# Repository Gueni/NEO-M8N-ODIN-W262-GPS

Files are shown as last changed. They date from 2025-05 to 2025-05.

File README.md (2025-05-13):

# GPS Module with PS/2 Programming Trigger
This project features a dual GPS/Bluetooth PCB design using:

- **NEO-M8N** (Part: `672-NEO-M8N-0TR-ND`) for GNSS positioning  
- **ODIN-W262** (Part: `672-ODIN-W262-05BTR-ND`) for Bluetooth communication  
- A custom **PS/2-based connector** to enable programming mode automatically via pin shorting

<p align="center">
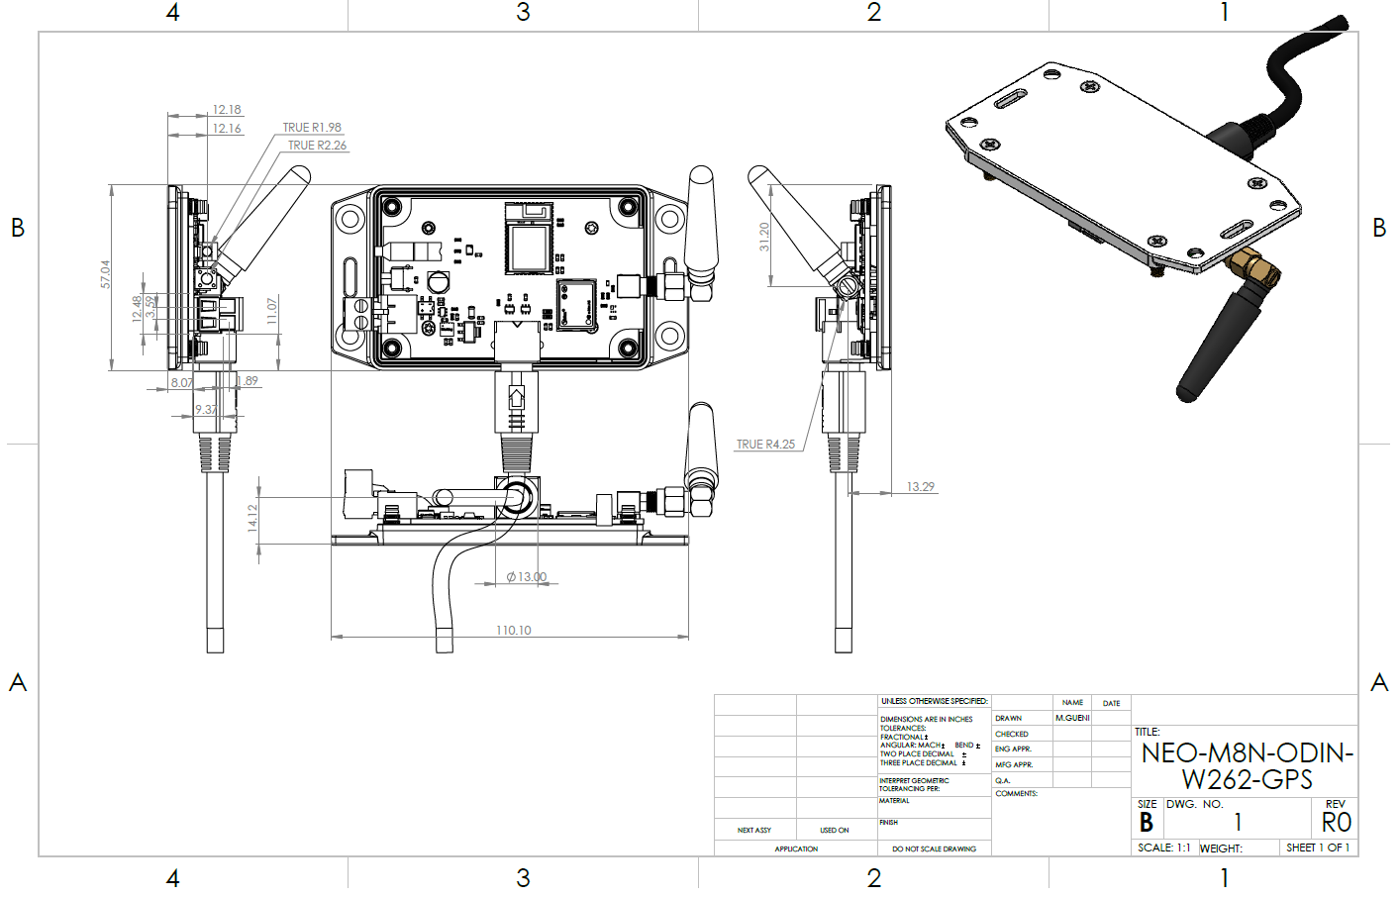
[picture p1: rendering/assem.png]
  
</p>

The system is compact, enclosed, and fully programmable without disassembly — using a smart GND-detection feature via the PS/2 port.

---
<p align="center">
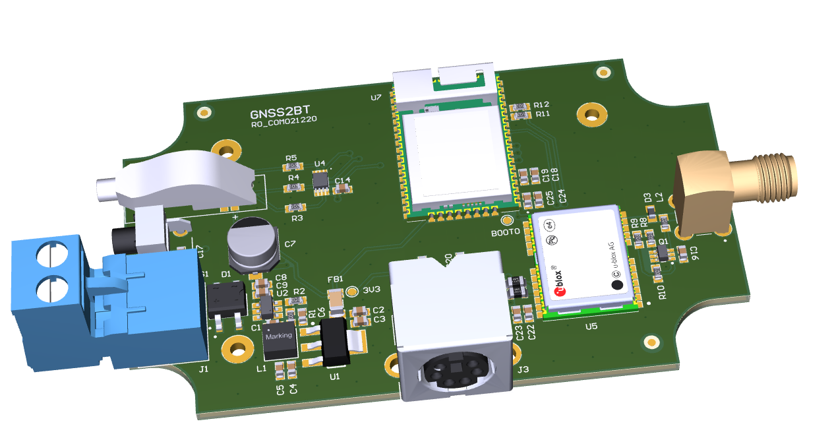
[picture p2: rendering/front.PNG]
  
</p>

## 💡 Features

- **GPS**: Multi-GNSS (GPS, GLONASS, Galileo, BeiDou) via NEO-M8N
- **Bluetooth**: Dual-mode BLE + classic via ODIN-W262
- **Enclosure**: Compact PCB with enclosure support
- **Programming Mode**: Automatically enabled when PS/2 connector is plugged in — GND pin shorts internal detection line
- **Power**: 3.3V operation with onboard LDO regulators
- **I/O**: Exposed UART for debug or data streaming
- **Connector**: 6-pin PS/2 Mini-DIN style programming interface

---

<p align="center">
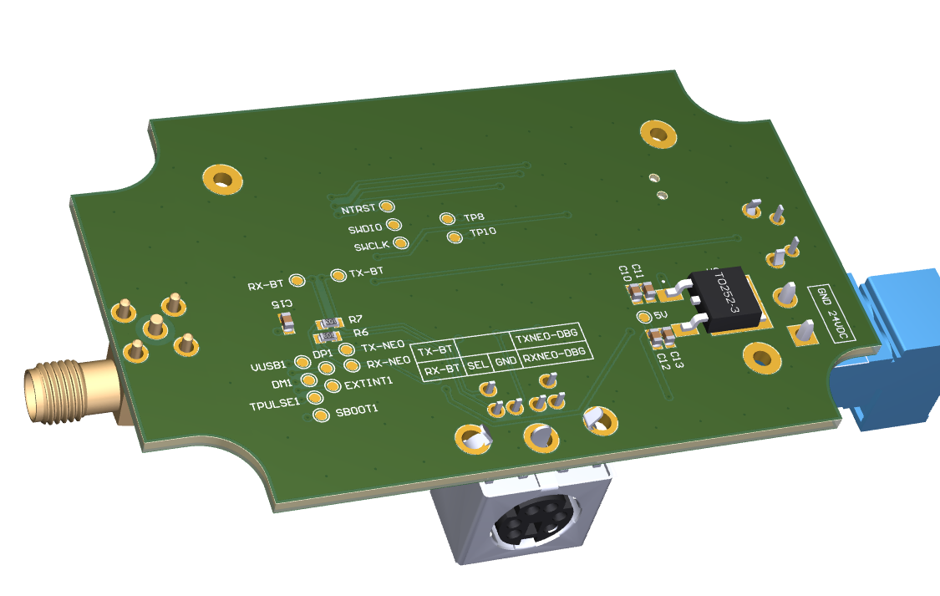
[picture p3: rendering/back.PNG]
  
</p>

## 🔌 Pinout (PS/2 Connector)

| PS/2 Pin | Function |
|---|---|
| Pin 1 | VCC (3.3V) |
| Pin 2 | TX (to programmer) |
| Pin 3 | RX (from programmer) |
| Pin 4 | GND |
| Pin 5 | GND detect (shorted when inserted) |
| Pin 6 | NC / Reserved |

*Ensure the PS/2 plug is inserted fully to engage GND detect pin.*

---

<p align="center">
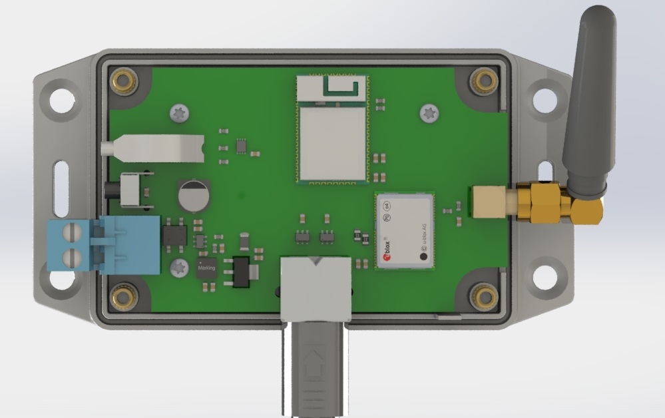
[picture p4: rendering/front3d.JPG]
  
</p>

<p align="center">
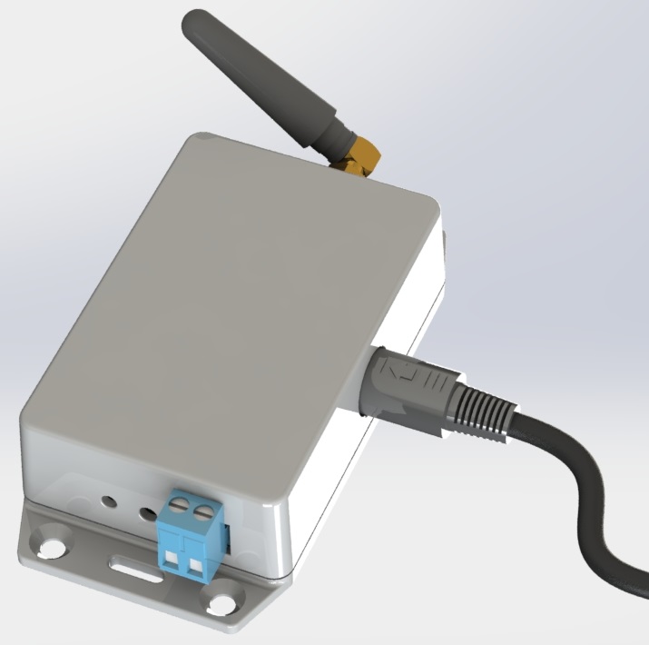
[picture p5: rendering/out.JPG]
  
</p>

<p align="center">
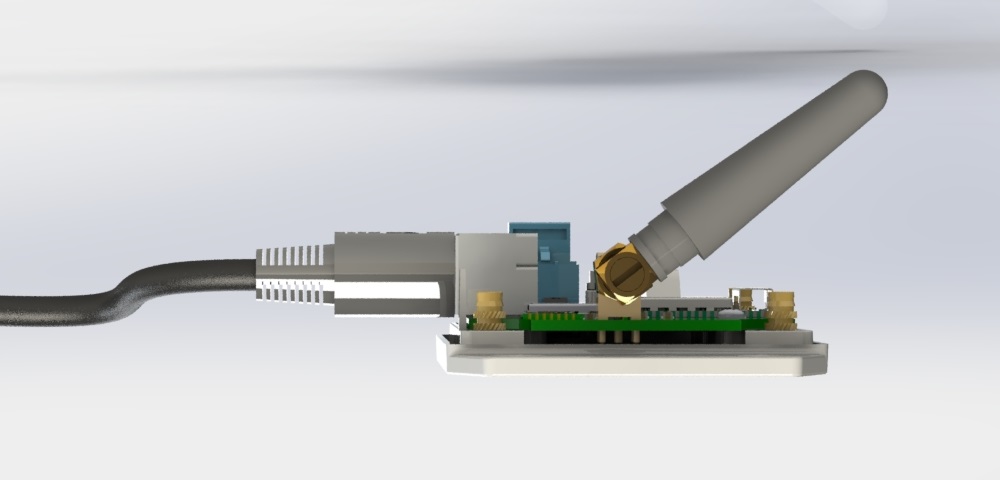
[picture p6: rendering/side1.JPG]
  
</p>

## 🛠 Programming Instructions

1. Plug in the PS/2 connector from the programming device.
2. This triggers programming mode automatically.
3. Use the provided UART interface at 3.3V levels.
4. Flash via standard tools (e.g., STM32CubeProgrammer, esptool.py, depending on MCU).

---

<p align="center">
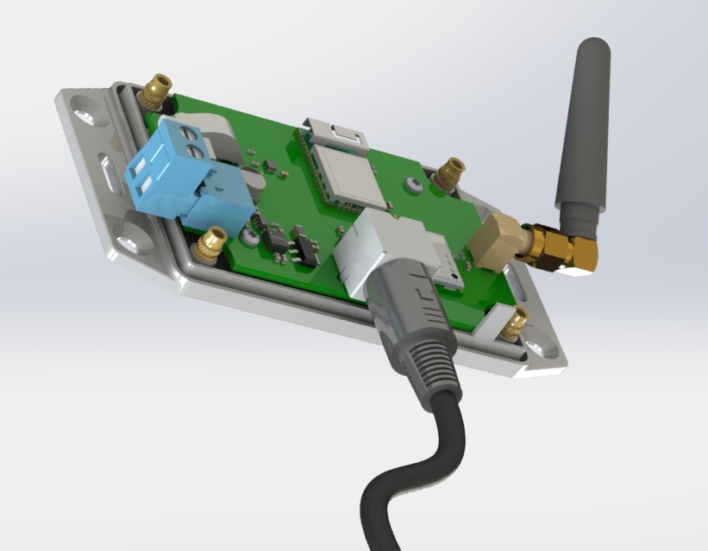
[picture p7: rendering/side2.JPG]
  
</p>

<p align="center">
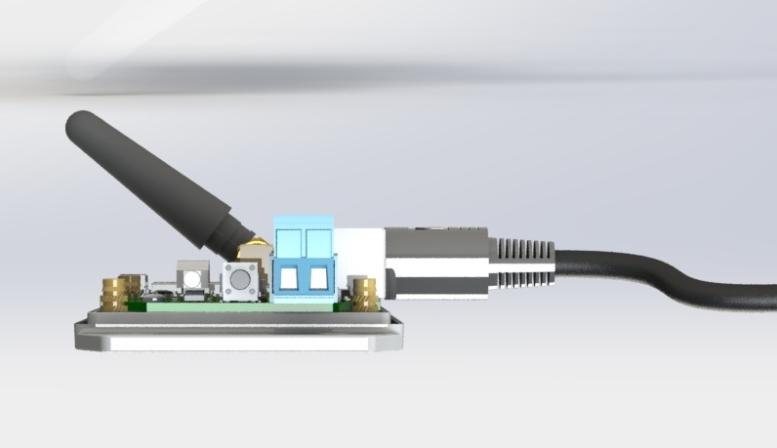
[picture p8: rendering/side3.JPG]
  
</p>

## 🧪 Testing & Debug

- LED indicators show GNSS fix and BT activity
- Test programming mode with multimeter: verify GND detect line goes LOW when PS/2 is inserted
- Firmware should check the GND detect pin at startup to enter bootloader

---

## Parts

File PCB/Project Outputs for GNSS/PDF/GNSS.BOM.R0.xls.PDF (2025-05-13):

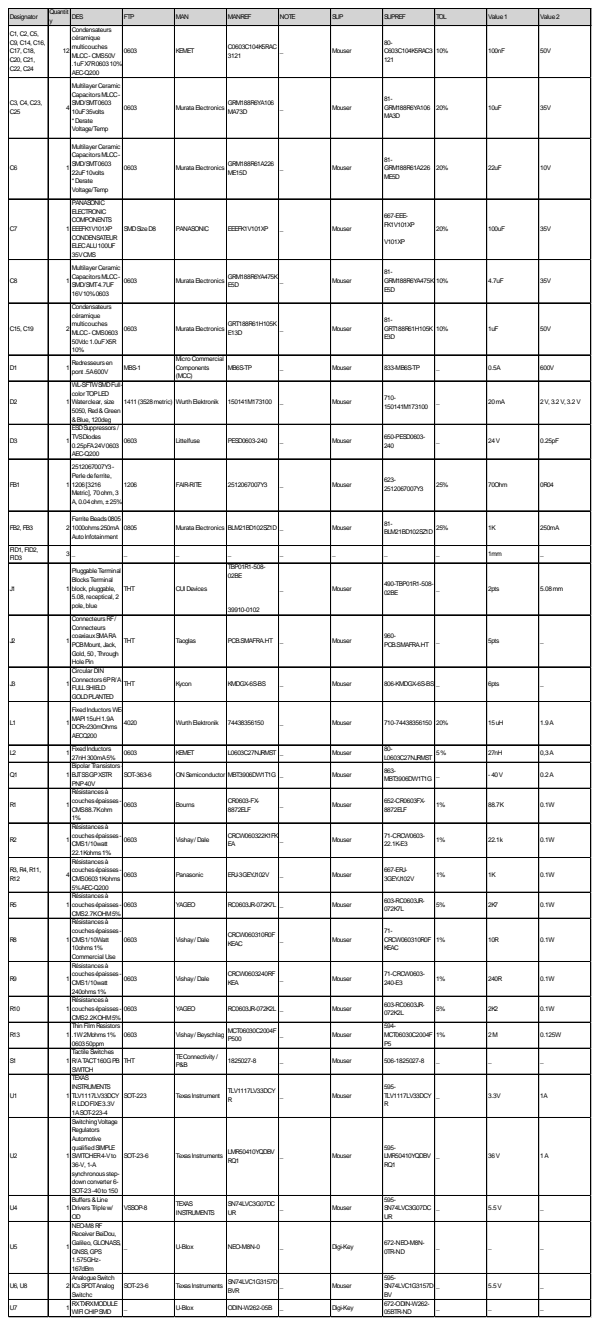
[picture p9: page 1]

Designator | Quantit y | DES | FTP | MAN | MANREF | NOTE | SUP | SUPREF | TOL | Value1 | Value2

C1, C2, C5, C9, C14, C16, C17, C18, C20, C21, C22, C24 | 12 | Condensateurs céramique multicouches MLCC- CMS50V .1uFX7R060310% AEC-Q200 | 0603 | KEMET | C0603C104K5RAC 3121 | _ | Mouser | 80-C603C104K5RAC3 121 | 10% | 100nF | 50V

C3, C4, C23, C25 | | Multilayer Ceramic Capacitors MLCC-SMD/SMT0603 4 10uF35volts *Derate Voltage/Temp | 0603 | MurataElectronics | GRM188R6YA106 MA73D | _ | Mouser | 81-GRM188R6YA106 MA3D | 20% | 10uF | 35V

C6 | | Multilayer Ceramic Capacitors MLCC-1 SMD/SMT0603 22uF10volts *Derate Voltage/Temp | 0603 | MurataElectronics | GRM188R61A226 ME15D | _ | Mouser | 81-GRM188R61A226 ME5D | 20% | 22uF | 10V

C7 | | PANASONIC ELECTRONIC COMPONENTS 1 EEEFK1V101XP CONDENSATEUR ELECALU100UF 35VCMS | SMDSizeD8 | PANASONIC | EEEFK1V101XP | _ | Mouser | 667-EEE-FK1V101XP V101XP | 20% | 100uF | 35V

C8 | | Multilayer Ceramic Capacitors MLCC-1 SMD/SMT4.7UF 16V10%0603 | 0603 | MurataElectronics | GRM188R6YA475K E5D | _ | Mouser | 81-GRM188R6YA475K E5D | 10% | 4.7uF | 35V

C15, C19 | | Condensateurs céramique multicouches 2 MLCC- CMS0603 50Vdc 1.0uFX5R 10% | 0603 | MurataElectronics | GRT188R61H105K E13D | _ | Mouser | 81-GRT188R61H105K E3D | 10% | 1uF | 50V

D1 | | 1 Redresseurs en pont .5A600V | MBS-1 | Micro Commercial Components (MCC) | MB6S-TP | _ | Mouser | 833-MB6S-TP | _ | 0.5A | 600V

D2 | | WL-SFTWSMDFull-color TOPLED 1 Waterclear, size 5050, Red&Green &Blue, 120deg | 1411(3528metric) | WurthElektronik | 150141M173100 | _ | Mouser | 710-150141M173100 | _ | 20mA | 2V, 3.2V, 3.2V

D3 | | ESDSuppressors / TVSDiodes 1 0.25pFA24V0603 AEC-Q200 | 0603 | Littelfuse | PESD0603-240 | _ | Mouser | 650-PESD0603-240 | _ | 24V | 0.25pF

FB1 | | 2512067007Y3-Perle deferrite, 1 1206[3216 Metric], 70ohm, 3 A, 0.04ohm, ±25% | 1206 | FAIR-RITE | 2512067007Y3 | _ | Mouser | 623-2512067007Y3 | 25% | 70Ohm | 0R04

FB2, FB3 | | FerriteBeads0805 2 1000ohms250mA AutoInfotainment | 0805 | MurataElectronics | BLM21BD102SZ1D | _ | Mouser | 81-BLM21BD102SZ1D | 25% | 1K | 250mA

FID1, FID2, FID3 | | 3 _ | _ | _ | _ | _ | _ | _ | _ | 1mm | _

J1 | | PluggableTerminal BlocksTerminal 1 block, pluggable, 5.08, receptical, 2 pole, blue | THT | CUIDevices | TBP01R1-508-02BE 39910-0102 | _ | Mouser | 490-TBP01R1-508-02BE | _ | 2pts | 5.08mm

J2 | | ConnecteursRF/ Connecteurs coaxiauxSMARA 1 PCBMount, Jack, Gold, 50, Through HolePin | THT | Taoglas | PCB.SMAFRA.HT | _ | Mouser | 960-PCB.SMAFRA.HT | _ | 5pts | _

J3 | | Circular DIN Connectors 6PR/A 1 FULLSHIELD GOLDPLANTED | THT | Kycon | KMDGX-6S-BS | _ | Mouser | 806-KMDGX-6S-BS _ | | 6pts | _

L1 | | FixedInductorsWE-MAPI15uH1.9A 1 DCR=230mOhms AECQ200 | 4020 | WurthElektronik | 74438356150 | _ | Mouser | 710-74438356150 | 20% | 15uH | 1.9A

L2 | | 1 FixedInductors 27nH300mA5% | 0603 | KEMET | L0603C27NJRMST | _ | Mouser | 80-L0603C27NJRMST | 5% | 27nH | 0,3A

Q1 | | Bipolar Transistors -1 BJTSSGPXSTR PNP40V | SOT-363-6 | ONSemiconductor | MBT3906DW1T1G | _ | Mouser | 863-MBT3906DW1T1G | _ | - 40V | 0.2A

R1 | | Résistancesà couchesépaisses-1 CMS88.7Kohm 1% | 0603 | Bourns | CR0603-FX-8872ELF | _ | Mouser | 652-CR0603FX-8872ELF | 1% | 88.7K | 0.1W

R2 | | Résistancesà 1 couchesépaisses-CMS1/10watt 22.1Kohms1% | 0603 | Vishay/ Dale | CRCW060322K1FK EA | _ | Mouser | 71-CRCW0603-22.1K-E3 | 1% | 22.1k | 0.1W

R3, R4, R11, R12 | | Résistancesà 4 couchesépaisses-CMS06031Kohms 5%AEC-Q200 | 0603 | Panasonic | ERJ-3GEYJ102V | _ | Mouser | 667-ERJ-3GEYJ102V | 1% | 1K | 0.1W

R5 | | Résistancesà 1 couchesépaisses-CMS2.7KOHM5% | 0603 | YAGEO | RC0603JR-072K7L | _ | Mouser | 603-RC0603JR-072K7L | 5% | 2K7 | 0.1W

R8 | | Résistancesà couchesépaisses-1 CMS1/10Watt 10ohms1% Commercial Use | 0603 | Vishay/ Dale | CRCW060310R0F KEAC | _ | Mouser | 71-CRCW060310R0F KEAC | 1% | 10R | 0.1W

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

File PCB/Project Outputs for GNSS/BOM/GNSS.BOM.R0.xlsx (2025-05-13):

Liste achat |  | Field=Title
Projet |  | Client | Date rapport
GNSS |  | Field=Client | Field=ReportDate
Version |  | Code Client | Date impression
R0 |  | Field=CodeClient | 2020-12-11
Ref Fabricant | Fabricant | Description | Designation | Quantité | Value 1 | Value 2 | Tolerance | Footprint | Fournisseur | Ref Fournisseur | Note
C0603C104K5RAC3121 | KEMET | Condensateurs céramique multicouches MLCC - CMS 50V .1uF X7R 0603 10% AEC-Q200 | C1, C2, C5, C9, C11, C12, C13, C14, C16, C17, C18, C20, C21, C22, C24 | 15 | 100nF | 50V | 10% | 0603 | Mouser | 80-C603C104K5RAC3121 | _
GRM188R6YA106MA73D | Murata Electronics | Multilayer Ceramic Capacitors MLCC - SMD/SMT 0603 10uF 35volts *Derate Voltage/Temp | C3, C4, C10, C23, C25 | 5 | 10uF | 35V | 20% | 0603 | Mouser | 81-GRM188R6YA106MA3D | _
GRM188R61A226ME15D | Murata Electronics | Multilayer Ceramic Capacitors MLCC - SMD/SMT 0603 22uF 10volts *Derate Voltage/Temp | C6 | 1 | 22uF | 10V | 20% | 0603 | Mouser | 81-GRM188R61A226ME5D | _
EEEFK1V101XP | PANASONIC | PANASONIC ELECTRONIC COMPONENTS EEEFK1V101XP CONDENSATEUR ELEC ALU 100UF 35V CMS | C7 | 1 | 100uF | 35V | 20% | SMD Size D8 | Mouser | 667-EEE-FK1V101XP V101XP | _
GRM188R6YA475KE5D | Murata Electronics | Multilayer Ceramic Capacitors MLCC - SMD/SMT 4.7UF 16V 10% 0603 | C8 | 1 | 4.7uF | 35V | 10% | 0603 | Mouser | 81-GRM188R6YA475KE5D | _
GRT188R61H105KE13D | Murata Electronics | Condensateurs céramique multicouches MLCC - CMS 0603 50Vdc 1.0uF X5R 10% | C15, C19 | 2 | 1uF | 50V | 10% | 0603 | Mouser | 81-GRT188R61H105KE3D | _
MB6S-TP | Micro Commercial Components (MCC) | Redresseurs en pont .5A 600V | D1 | 1 | 0.5A | 600V | _ | MBS-1 | Mouser | 833-MB6S-TP | _
150141M173100 | Wurth Elektronik | WL-SFTW SMD Full-color TOP LED Waterclear, size 5050, Red & Green & Blue, 120deg | D2 | 1 | 20 mA | 2 V, 3.2 V, 3.2 V | _ | 1411 (3528 metric) | Mouser | 710-150141M173100 | _
PESD0603-240 | Littelfuse | ESD Suppressors / TVS Diodes 0.25pFA 24V 0603 AEC-Q200 | D3 | 1 | 24 V | 0.25pF | _ | 0603 | Mouser | 650-PESD0603-240 | _
2512067007Y3 | FAIR-RITE | 2512067007Y3 - Perle de ferrite, 1206 [3216 Metric], 70 ohm, 3 A, 0.04 ohm, ± 25% | FB1 | 1 | 70Ohm | 0R04 | 25% | 1206 | Mouser | 623-2512067007Y3 | _
BLM21BD102SZ1D | Murata Electronics | Ferrite Beads 0805 1000ohms 250mA Auto Infotainment | FB2, FB3 | 2 | 1K | 250mA | 25% | 0805 | Mouser | 81-BLM21BD102SZ1D | _
_ | _ | _ | FID1, FID2, FID3 | 3 | 1mm | _ | _ | _ | _ | _ | _
TBP01R1-508-02BE | CUI Devices | Pluggable Terminal Blocks Terminal block, pluggable, 5.08, receptical, 2 pole, blue | J1 | 1 | 2pts | 5.08 mm | _ | THT | Mouser | 490-TBP01R1-508-02BE | _
PCB.SMAFRA.HT | Taoglas | Connecteurs RF / Connecteurs coaxiaux SMA RA PCB Mount, Jack, Gold, 50 , Through Hole Pin | J2 | 1 | 5pts | _ | _ | THT | Mouser | 960-PCB.SMAFRA.HT | _
KMDGX-6S-BS | Kycon | Circular DIN Connectors 6P R/A FULL SHIELD GOLD PLANTED | J3 | 1 | 6pts | _ | _ | THT | Mouser | 806-KMDGX-6S-BS | _
74438356150 | Wurth Elektronik | Fixed Inductors WE-MAPI 15uH 1.9A DCR=230mOhms AECQ200 | L1 | 1 | 15 uH | 1.9 A | 20% | 4020 | Mouser | 710-74438356150 | _
L0603C27NJRMST | KEMET | Fixed Inductors 27nH 300mA 5% | L2 | 1 | 27nH | 0,3 A | 5 % | 0603 | Mouser | 80-L0603C27NJRMST | _
MBT3906DW1T1G | ON Semiconductor | Bipolar Transistors - BJT SS GP XSTR PNP 40V | Q1 | 1 | - 40 V | 0.2 A | _ | SOT-363-6 | Mouser | 863-MBT3906DW1T1G
CR0603-FX-8872ELF | Bourns | Résistances à couches épaisses - CMS 88.7K ohm 1% | R1 | 1 | 88.7K | 0.1W | 1% | 0603 | Mouser | 652-CR0603FX-8872ELF | _
CRCW060322K1FKEA | Vishay / Dale | Résistances à couches épaisses - CMS 1/10watt 22.1Kohms 1% | R2 | 1 | 22.1k | 0.1W | 1% | 0603 | Mouser | 71-CRCW0603-22.1K-E3 | _
ERJ-3GEYJ102V | Panasonic | Résistances à couches épaisses - CMS 0603 1Kohms 5% AEC-Q200 | R3, R4, R11, R12 | 4 | 1K | 0.1W | 1% | 0603 | Mouser | 667-ERJ-3GEYJ102V | _
RC0603JR-072K7L | YAGEO | Résistances à couches épaisses - CMS 2.7K OHM 5% | R5 | 1 | 2K7 | 0.1W | 5% | 0603 | Mouser | 603-RC0603JR-072K7L | _
MCT06030Z0000ZP500 | Vishay / Beyschlag | Thin Film Resistors - SMD Zero ohm Jumper | R6, R7 | 2 | 0R | 0.125W | _ | 0603 | Mouser | 594-MCT06030Z0000ZP5 | _
CRCW060310R0FKEAC | Vishay / Dale | Résistances à couches épaisses - CMS 1/10Watt 10ohms 1% Commercial Use | R8 | 1 | 10R | 0.1W | 1% | 0603 | Mouser | 71-CRCW060310R0FKEAC | _
CRCW0603240RFKEA | Vishay / Dale | Résistances à couches épaisses - CMS 1/10watt 240ohms 1% | R9 | 1 | 240R | 0.1W | 1% | 0603 | Mouser | 71-CRCW0603-240-E3 | _
RC0603JR-072K2L | YAGEO | Résistances à couches épaisses - CMS 2.2K OHM 5% | R10 | 1 | 2K2 | 0.1W | 5% | 0603 | Mouser | 603-RC0603JR-072K2L | _
1825027-8 | TE Connectivity / P&B | Tactile Switches R/A TACT 160G PB SWITCH | S1 | 1 | _ | _ | _ | THT | Mouser | 506-1825027-8 | _
TLV1117LV33DCYR | Texas Instrument | TEXAS INSTRUMENTS TLV1117LV33DCYR LDO FIXE 3.3V 1A SOT-223-4 | U1 | 1 | 3.3V | 1A | _ | SOT-223 | Mouser | 595-TLV1117LV33DCYR | _
LMR50410YQDBVRQ1 | Texas Instruments | Switching Voltage Regulators Automotive qualified SIMPLE SWITCHER 4-V to 36-V, 1-A synchronous step-down converter 6-SOT-23 -40 to 150 | U2 | 1 | 36 V | 1 A | _ | SOT-23-6 | Mouser | 595-LMR50410YQDBVRQ1 | _
BD50C0AFP-CE2 | ROHM Semiconductor | LDO Voltage Regulators 4-26.5V TO252-3 15A LDO Regulator | U3 | 1 | 5V | 1A | _ | TO-252-3 | Mouser | 755-BD50C0AFP-CE2 | _
SN74LVC3G07DCUR | TEXAS INSTRUMENTS | Buffers & Line Drivers Triple w/ OD | U4 | 1 | 5.5 V | _ | _ | VSSOP-8 | Mouser | 595-SN74LVC3G07DCUR | _
NEO-M8N-0 | U-Blox | NEO-M8 RF Receiver BeiDou, Galileo, GLONASS, GNSS, GPS 1.575GHz -167dBm | U5 | 1 | _ | _ | _ | _ | Digi-Key | 672-NEO-M8N-0TR-ND | _
SN74LVC1G3157DBVR | Texas Instruments | Analogue Switch ICs SPDT Analog Switchc | U6, U8 | 2 | 5.5 V | _ | _ | SOT-23-6 | Mouser | 595-SN74LVC1G3157DBV | _
ODIN-W262-05B | U-Blox | RX TXRX MODULE WIFI CHIP SMD | U7 | 1 | _ | _ | _ | _ | Digi-Key | 672-ODIN-W262-05BTR-ND | _
MCT06030C2004FP500 | Vishay / Beyschlag | Thin Film Resistors .1W 2Mohms 1% 0603 50ppm | R13 |  | 2 M | 0.125W | 1% | 0603 | Mouser | 594-MCT06030C2004FP5 | _
 |  |  | MICRO DEVICE TUNISIE
 |  |  | Micro Device Tunisie S.A.R.L - Pépinière D'entreprise de Sousse, Sousse-Tec 4023 Sousse Tunisie
 |  |  | Phone : +216 73 302 800 | E-Mail : contact@mdtunisie.com | Website : www.mdtunisie.com

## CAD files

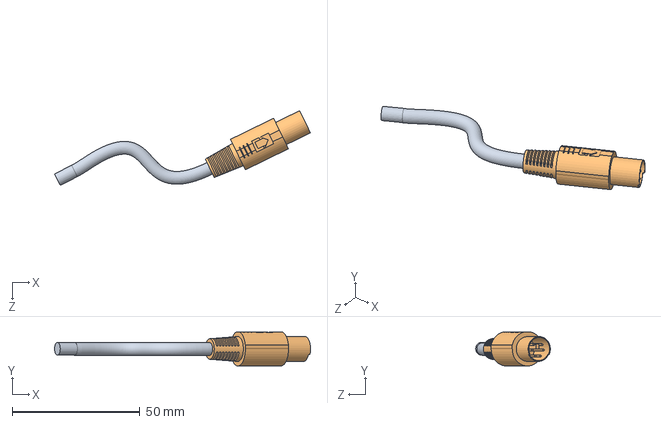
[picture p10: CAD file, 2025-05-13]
3D/Minidin 6.SLDASM
100.1 x 13.3 x 29.2 mm
Cable
Mini din 6

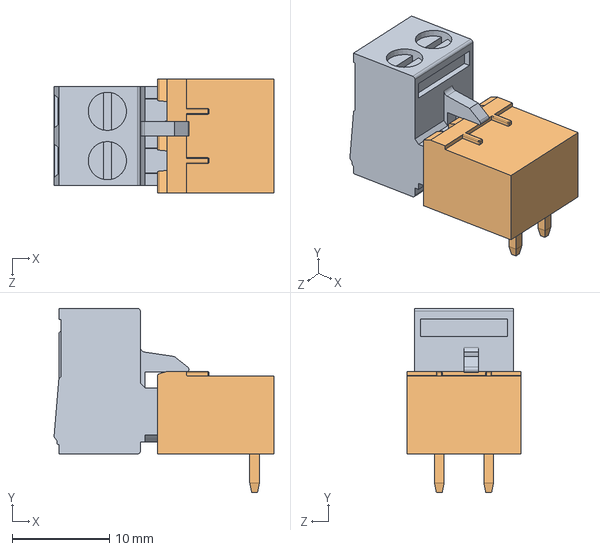
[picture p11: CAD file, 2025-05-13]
3D/Assem1.SLDASM
22.7 x 19.0 x 11.8 mm
CUI_DEVICES_TBP01P1-508-02BE
CUI_DEVICES_TBP01R1-508-02BE

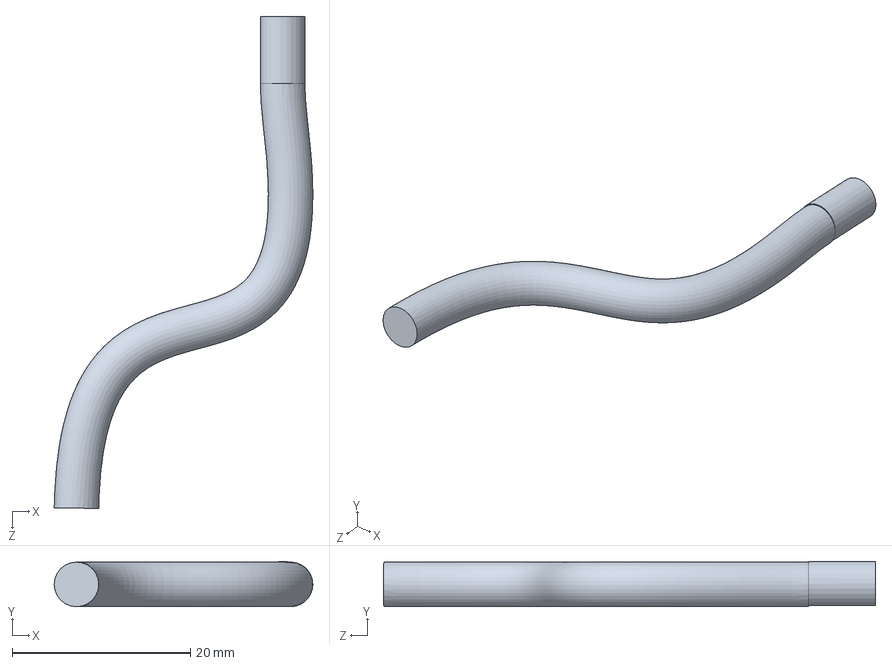
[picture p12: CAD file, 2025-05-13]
3D/Cable.SLDPRT
29.0 x 5.09 x 55.1 mm

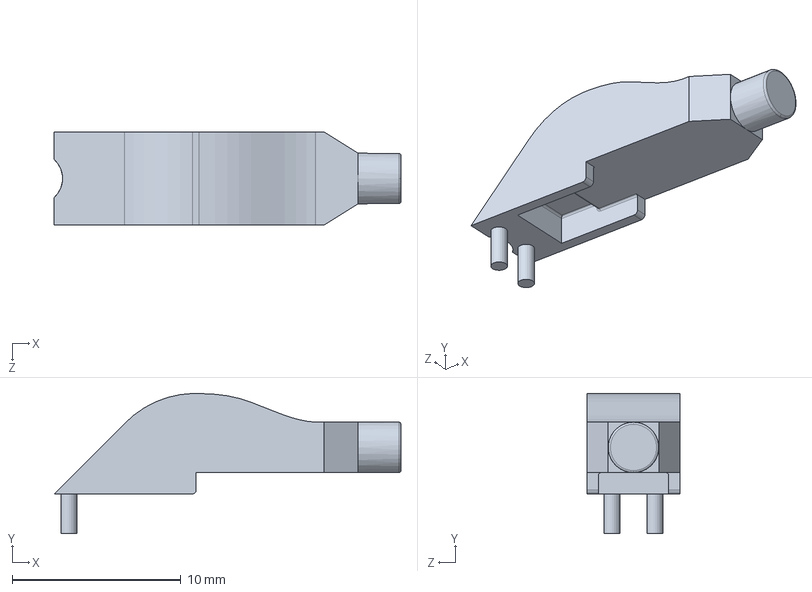
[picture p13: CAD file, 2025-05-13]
3D/User Library-BIVAR_SLP-1.SLDPRT
20.6 x 8.31 x 5.54 mm

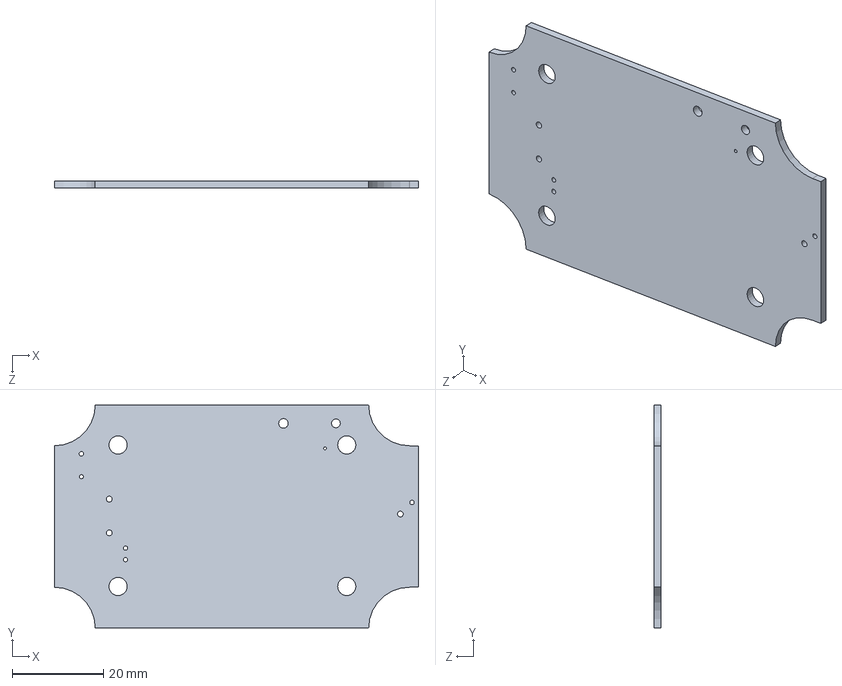
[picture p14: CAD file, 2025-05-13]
3D/Part29.SLDPRT
80.0 x 49.0 x 1.60 mm

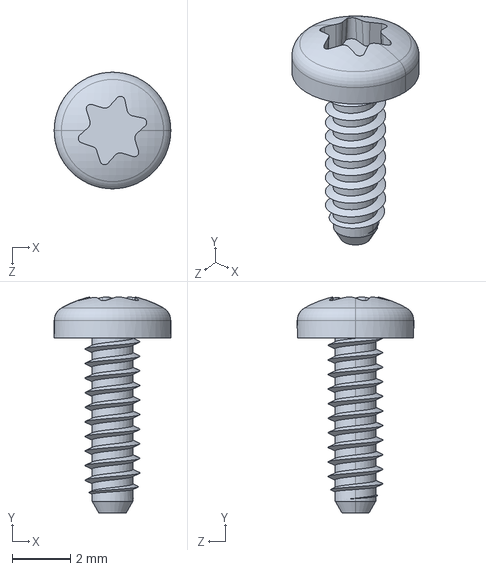
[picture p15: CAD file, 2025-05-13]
3D/M2 x 6mm TORX T6.step.SLDPRT
4.00 x 7.41 x 4.00 mm

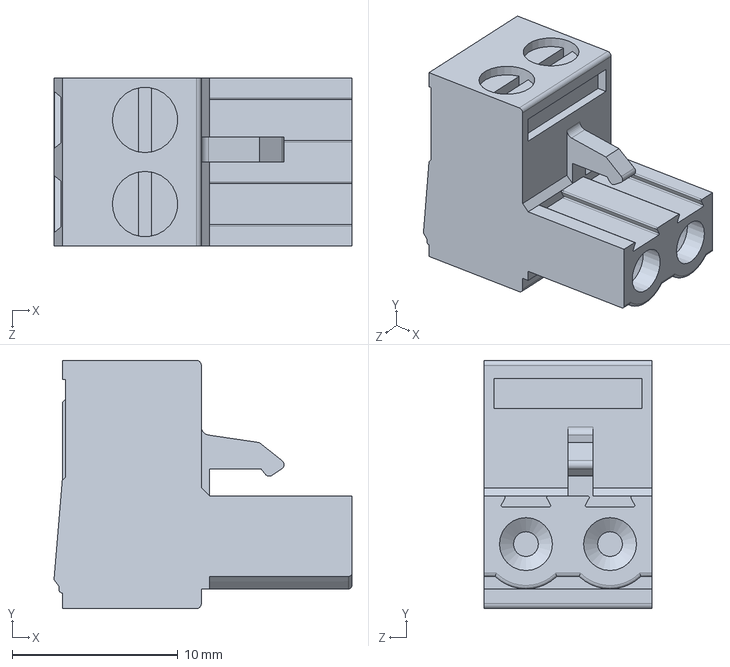
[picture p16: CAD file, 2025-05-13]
3D/CUI_DEVICES_TBP01P1-508-02BE.sldprt
18.0 x 15.0 x 10.2 mm

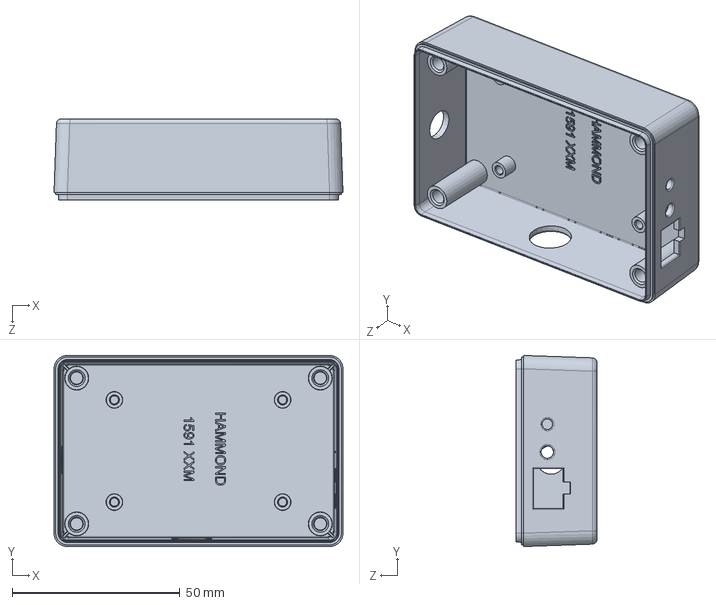
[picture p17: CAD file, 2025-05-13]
3D/Solid1.SLDPRT
86.2 x 57.0 x 24.2 mm

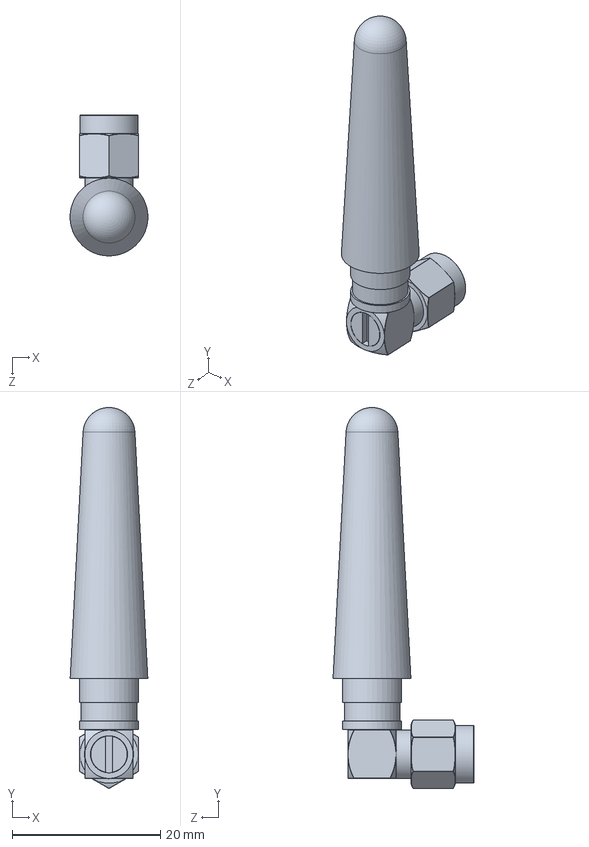
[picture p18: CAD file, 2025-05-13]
3D/User Library-Antenna AP24A.SLDPRT
10.5 x 51.4 x 19.0 mm

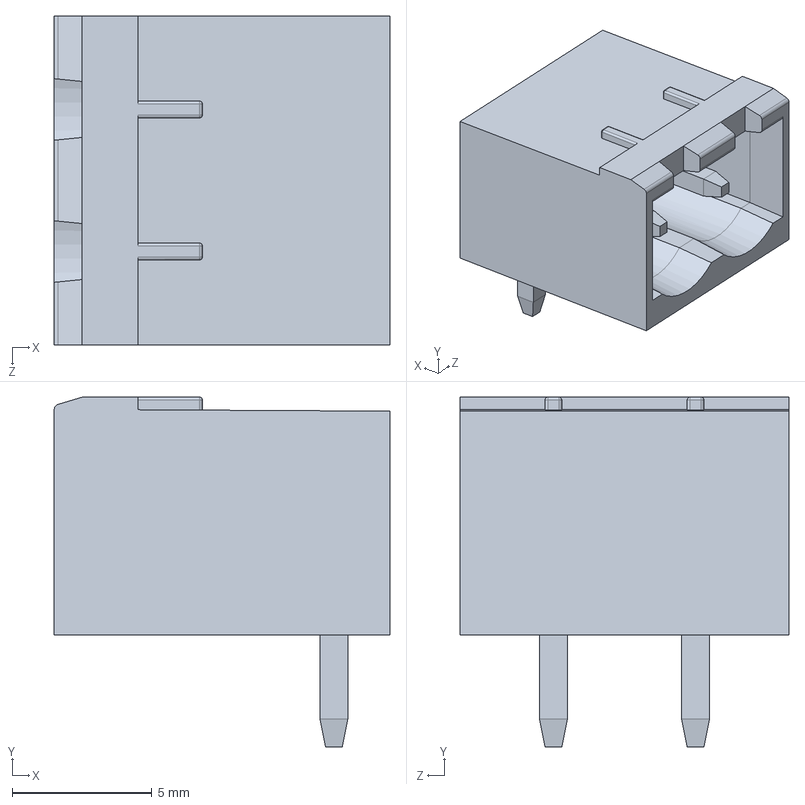
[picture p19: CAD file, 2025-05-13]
3D/CUI_DEVICES_TBP01R1-508-02BE.sldprt
12.0 x 12.5 x 11.8 mm

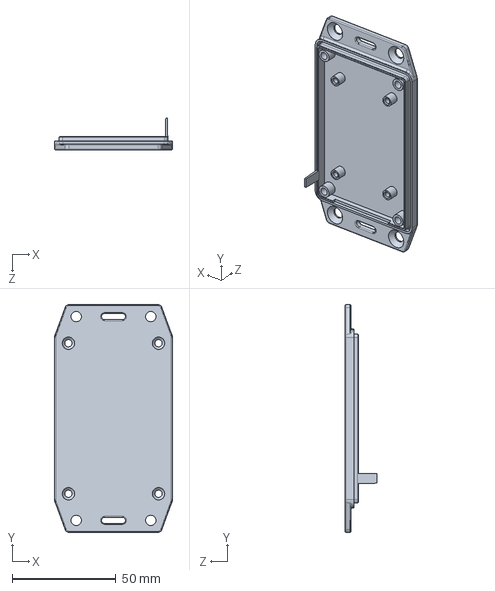
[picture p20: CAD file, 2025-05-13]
3D/Solid1-1.SLDPRT
57.0 x 110.1 x 15.6 mm

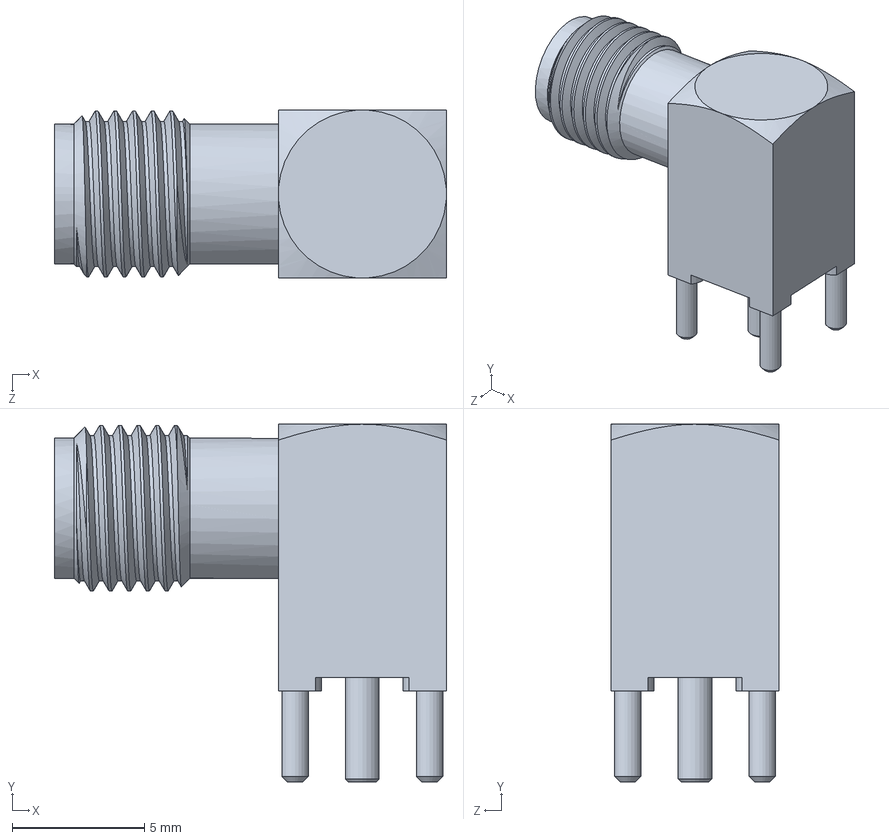
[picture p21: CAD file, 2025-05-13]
3D/733910083.stp.SLDPRT
14.8 x 13.5 x 6.35 mm

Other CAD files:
3D/Solid1-3.SLDPRT
3D/Solid1-2.SLDPRT
3D/Mini din 6.SLDPRT

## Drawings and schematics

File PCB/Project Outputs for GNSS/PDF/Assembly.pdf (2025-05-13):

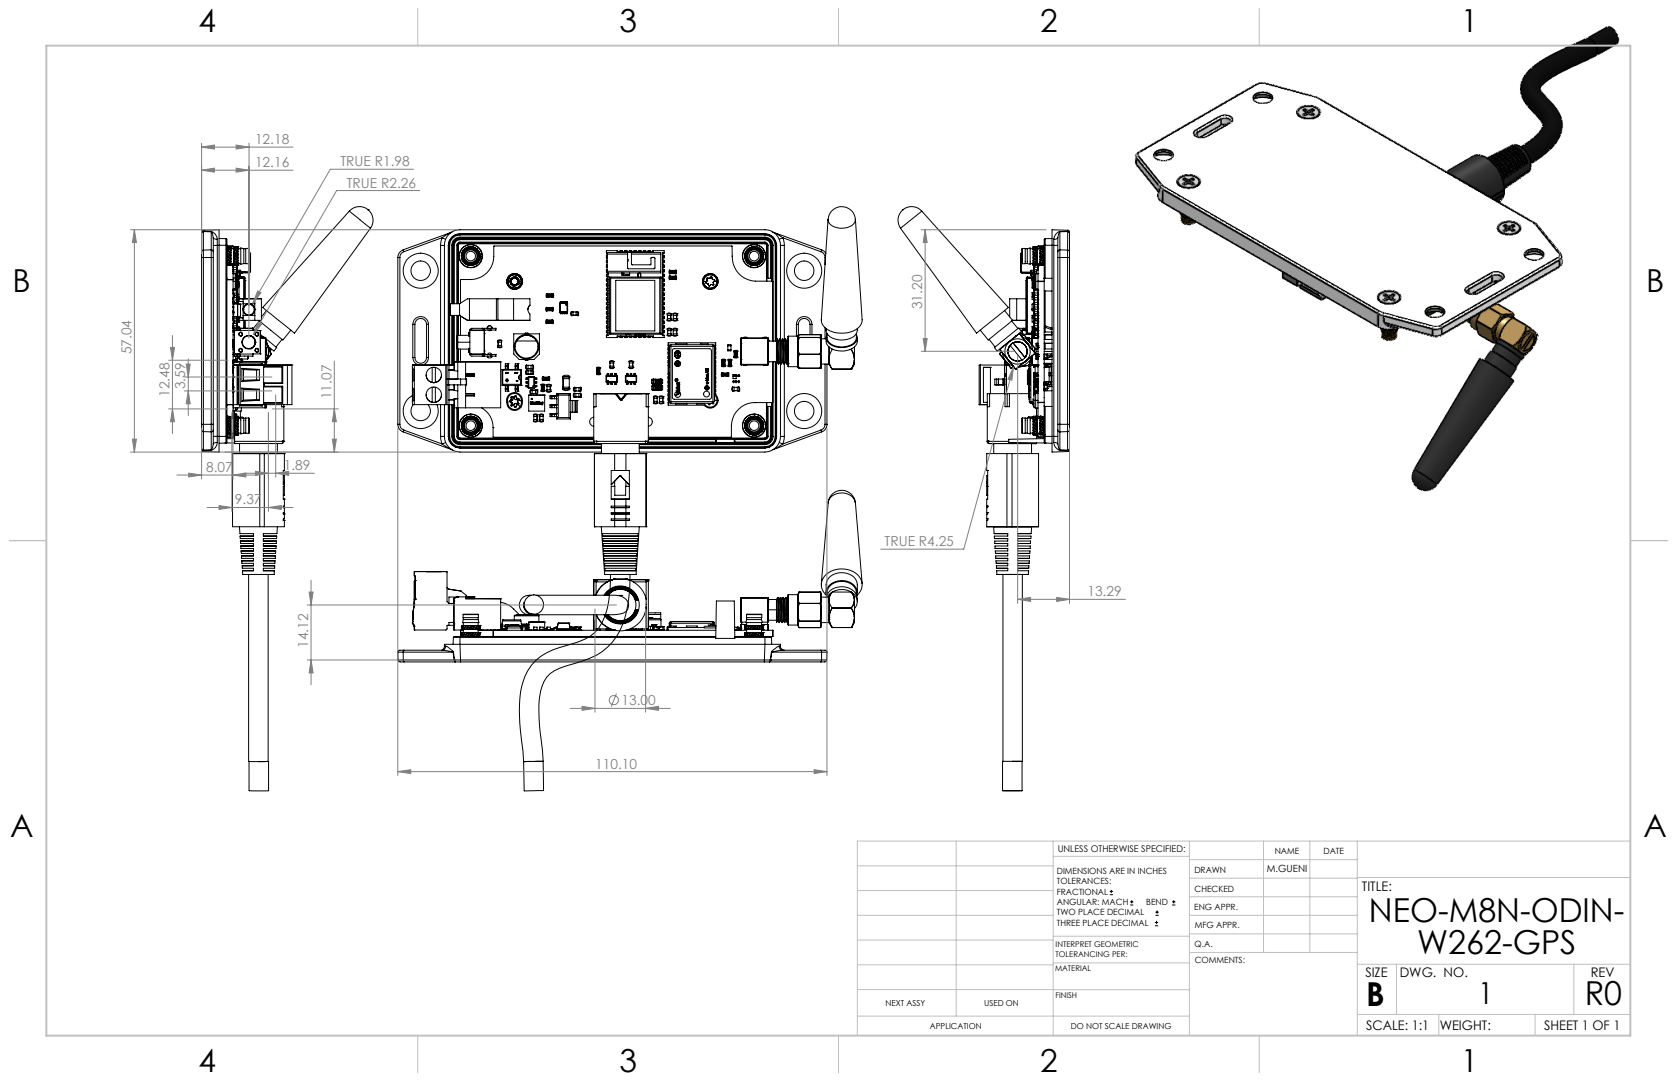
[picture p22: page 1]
TRUE R4.25; TRUE R2.26; TRUE R1.98

UNLESS OTHERWISE SPECIFIED: | | NAME | DATE
DIMENSIONS ARE IN INCHES TOLERANCES: FRACTIONAL ANGULAR: MACH BEND TWO PLACE DECIMAL THREE PLACE DECIMAL | DRAWN | M.GUENI

CHECKED | | | TITLE: NEO-M8N-ODIN-W262-GPS

ENG APPR.
MFG APPR.

INTERPRET GEOMETRIC TOLERANCING PER: | Q.A.
MATERIAL | | SIZE B | DWG. NO. 1 | REV R0

NEXT ASSY | USED ON | FINISH

APPLICATION | DO NOT SCALE DRAWING | | SCALE: 1:1 | WEIGHT: | SHEET 1 OF 1

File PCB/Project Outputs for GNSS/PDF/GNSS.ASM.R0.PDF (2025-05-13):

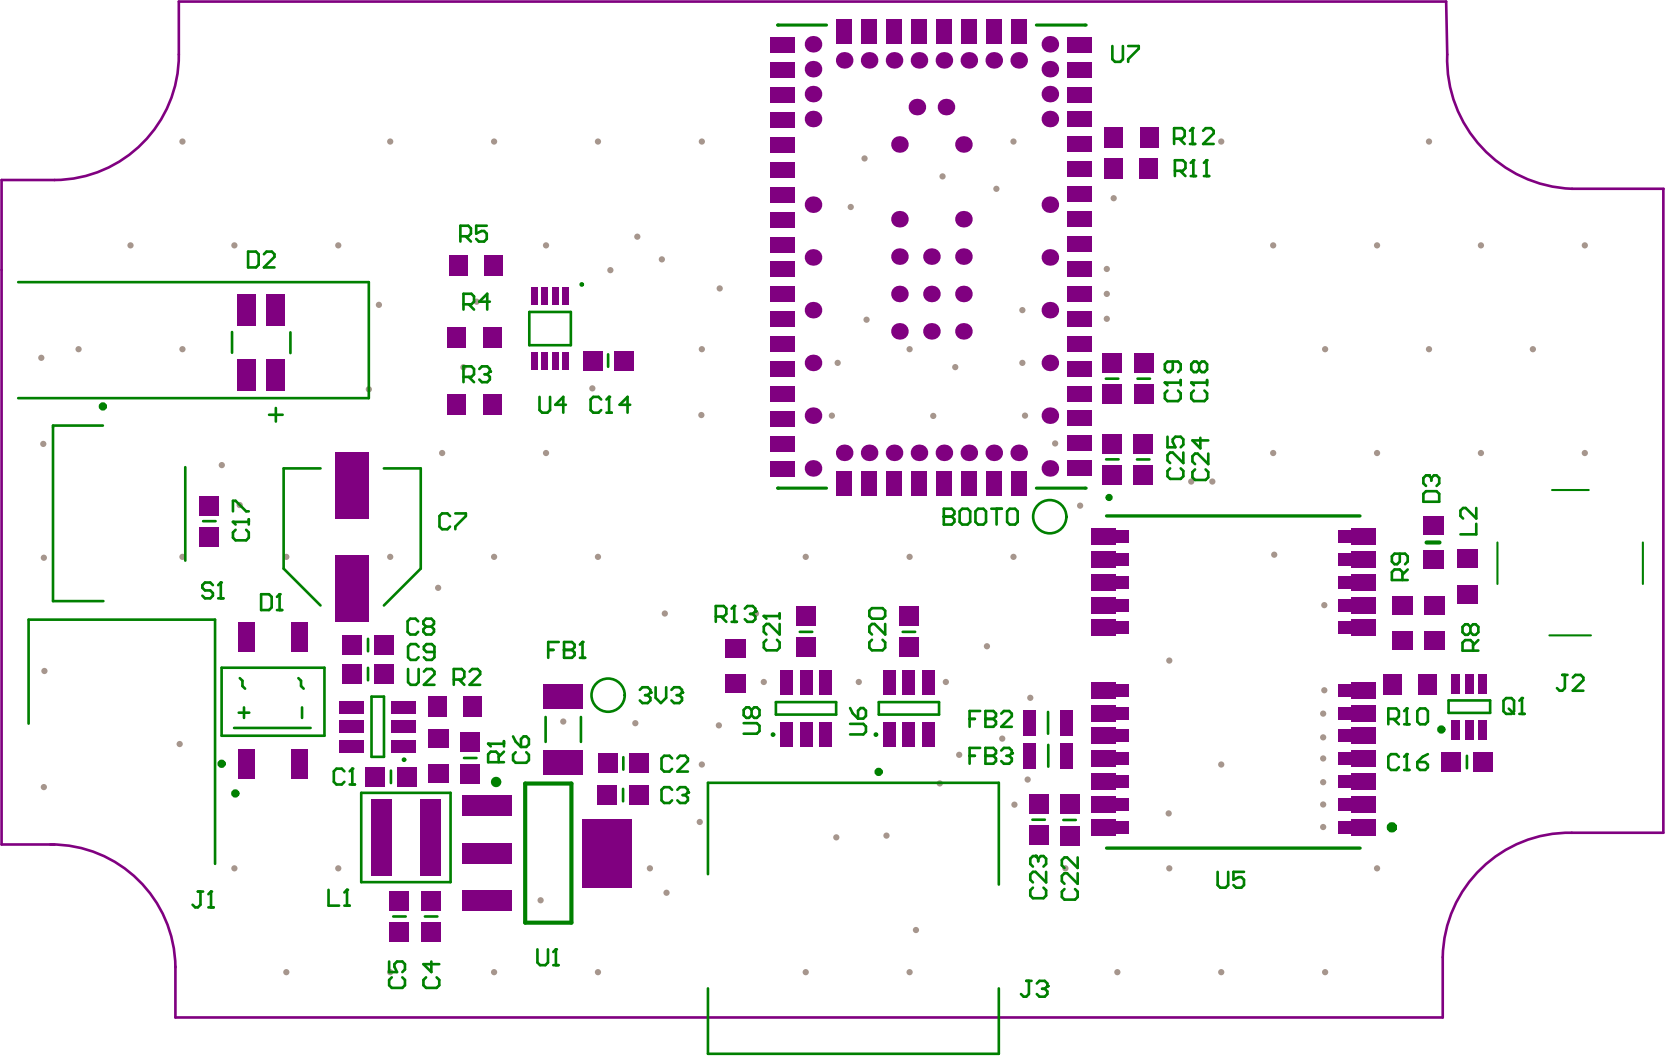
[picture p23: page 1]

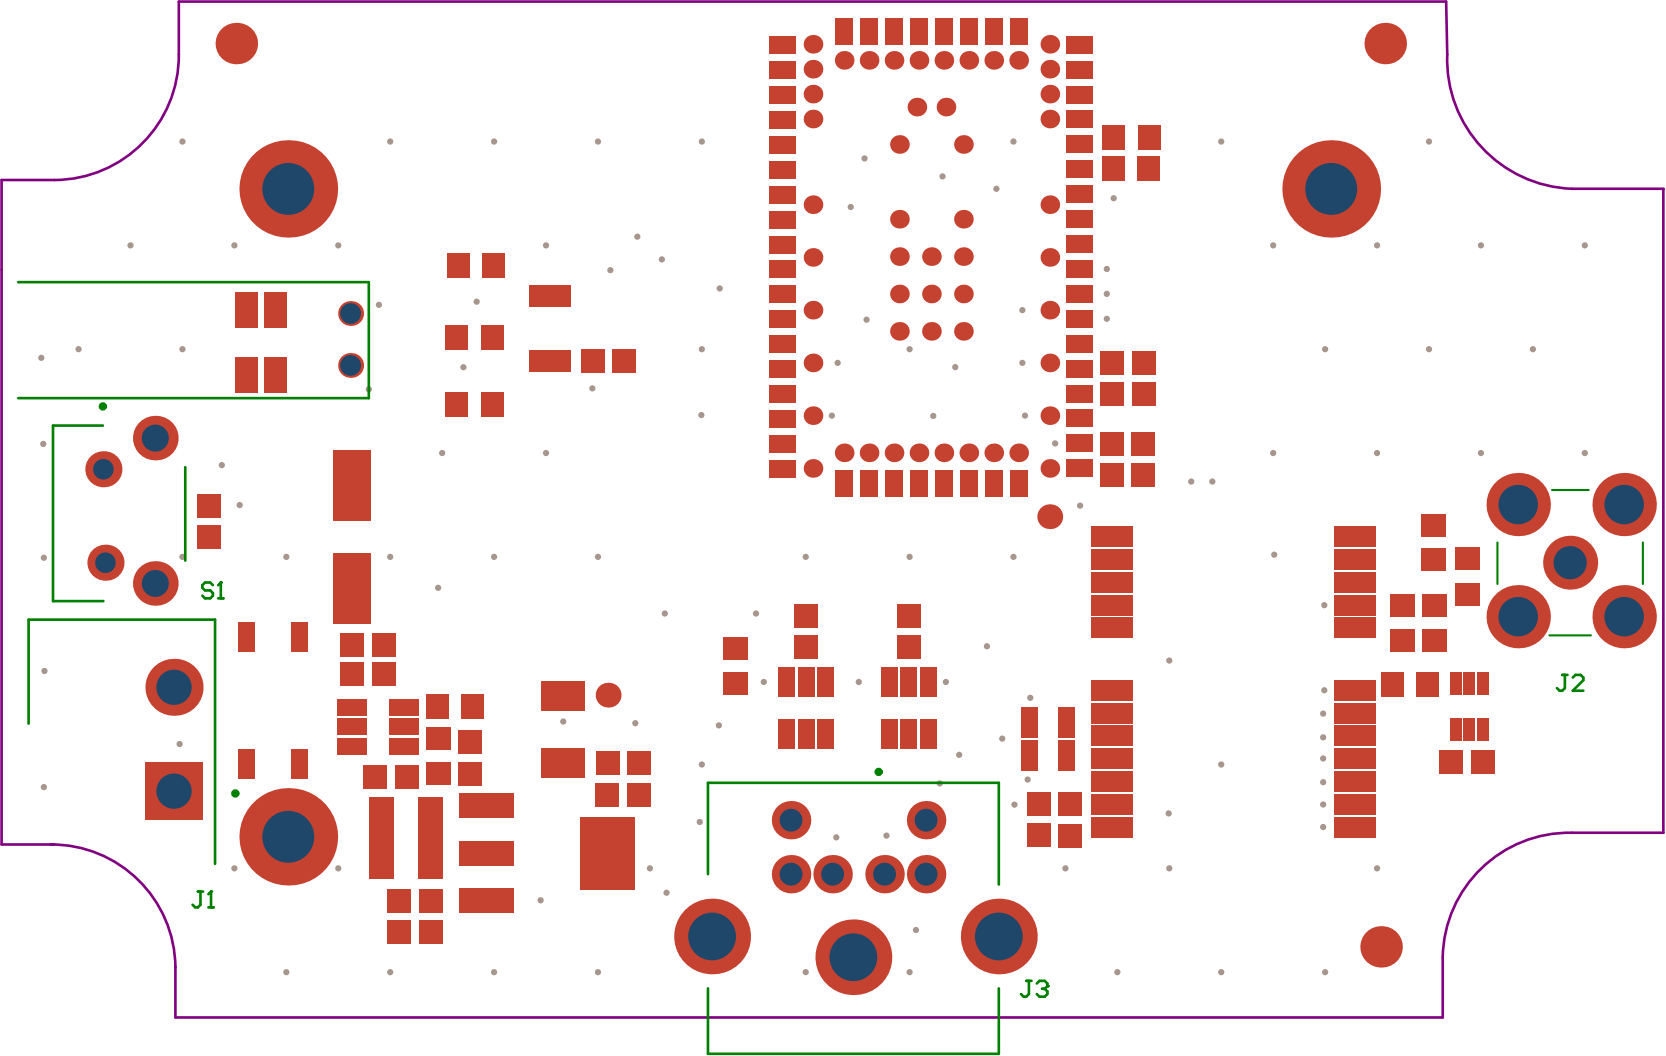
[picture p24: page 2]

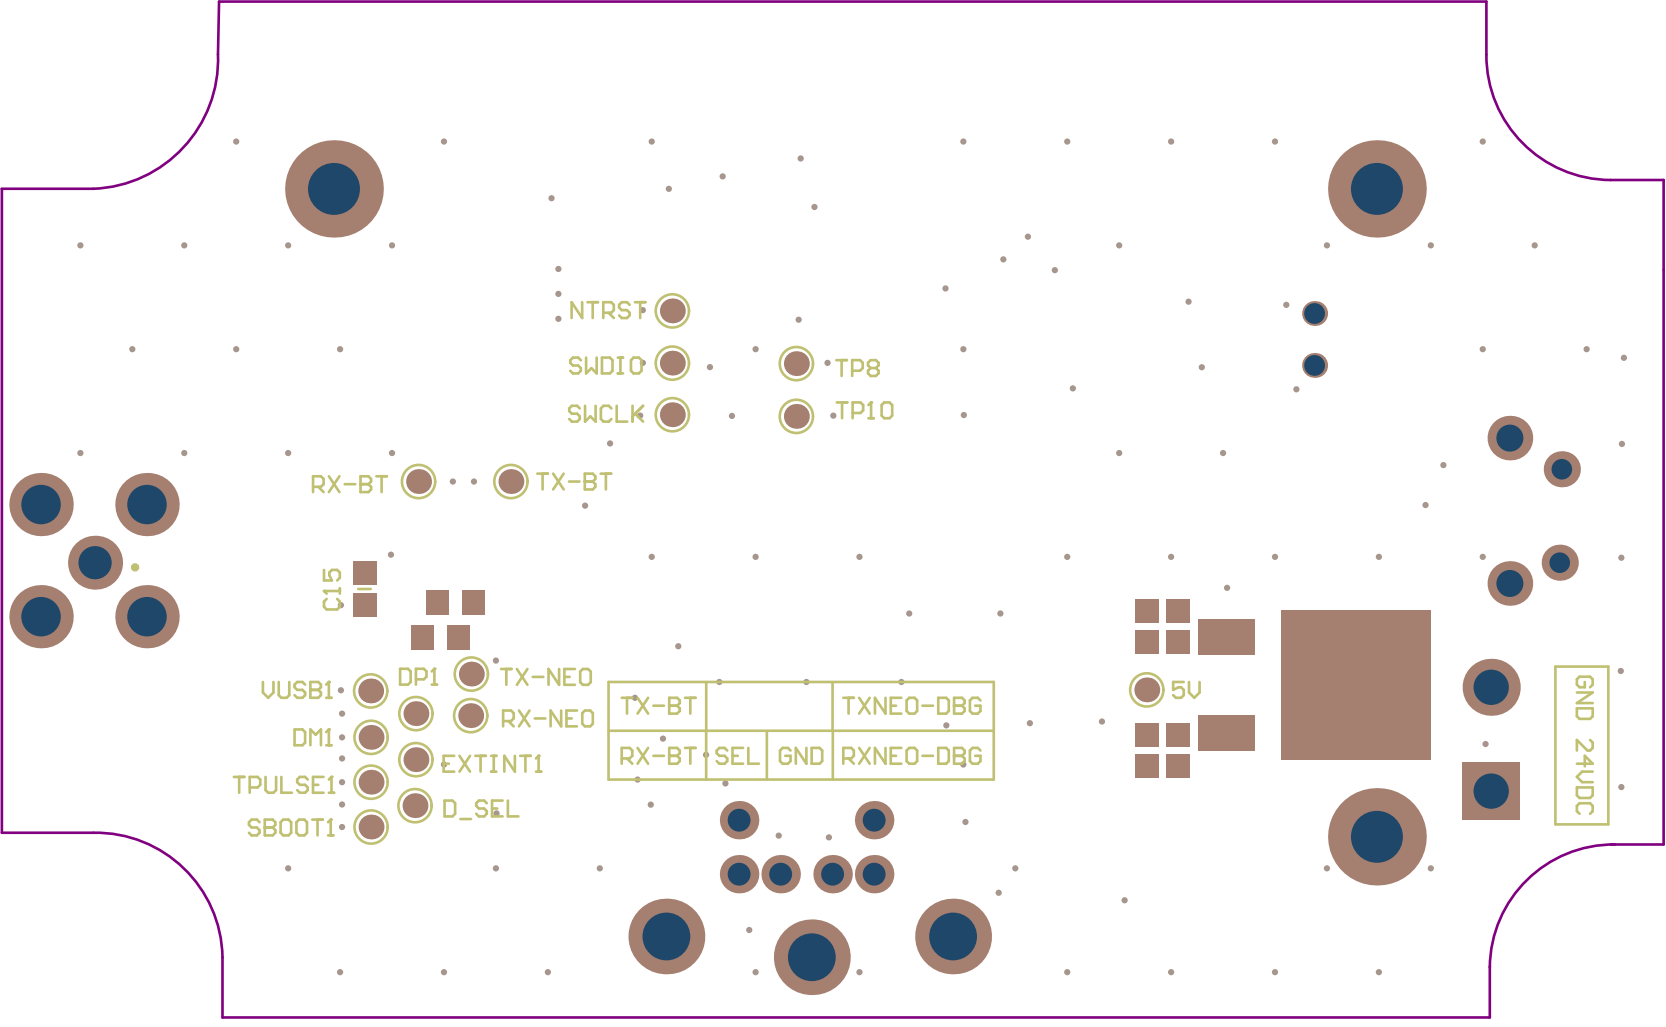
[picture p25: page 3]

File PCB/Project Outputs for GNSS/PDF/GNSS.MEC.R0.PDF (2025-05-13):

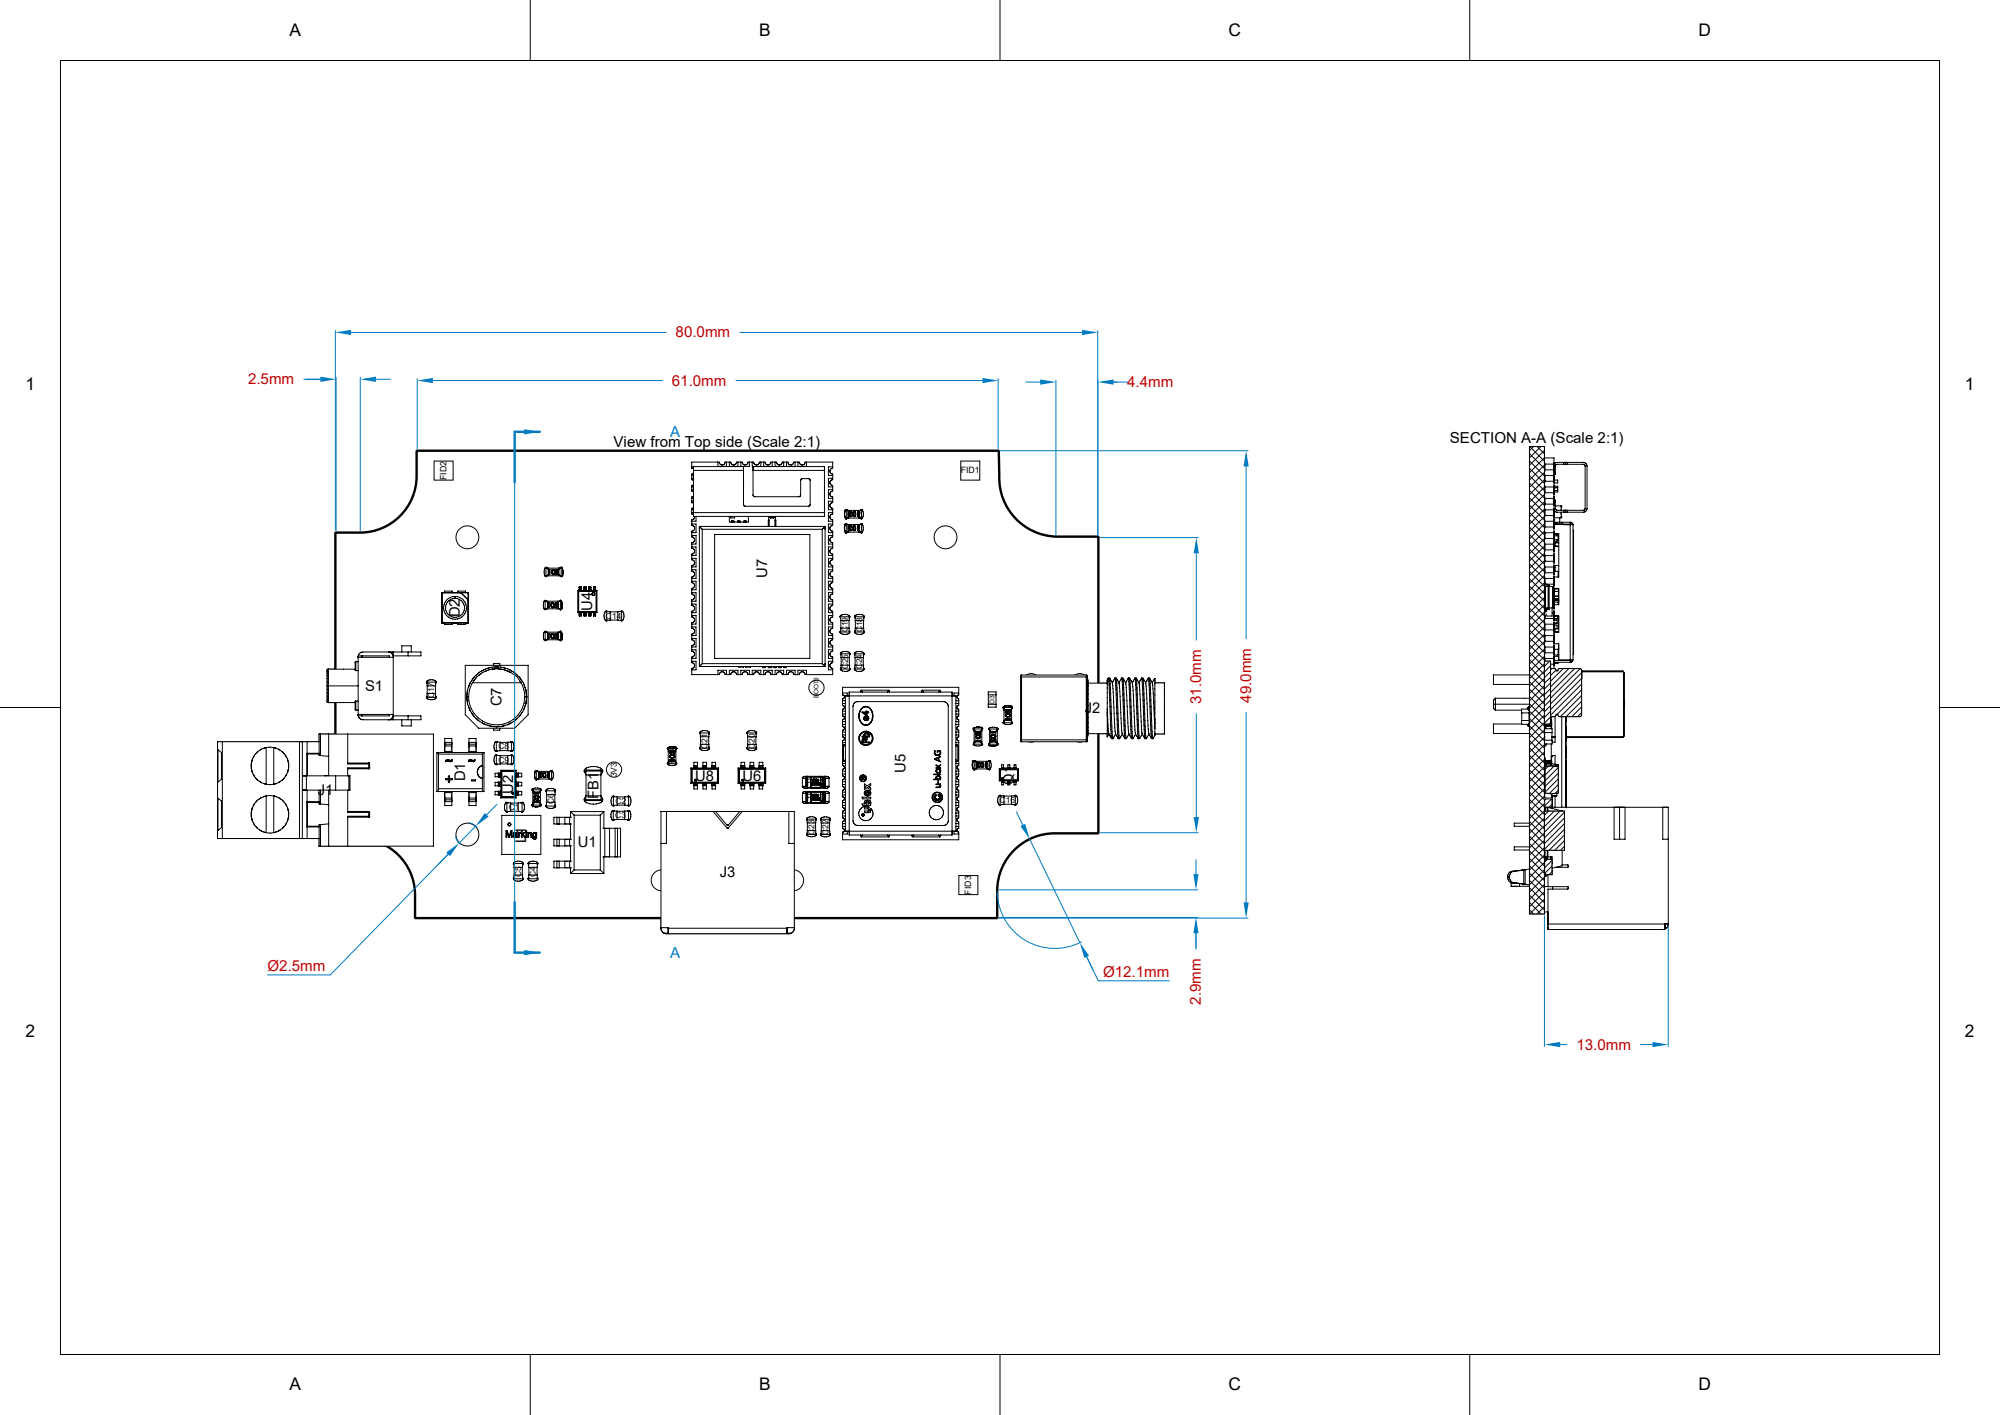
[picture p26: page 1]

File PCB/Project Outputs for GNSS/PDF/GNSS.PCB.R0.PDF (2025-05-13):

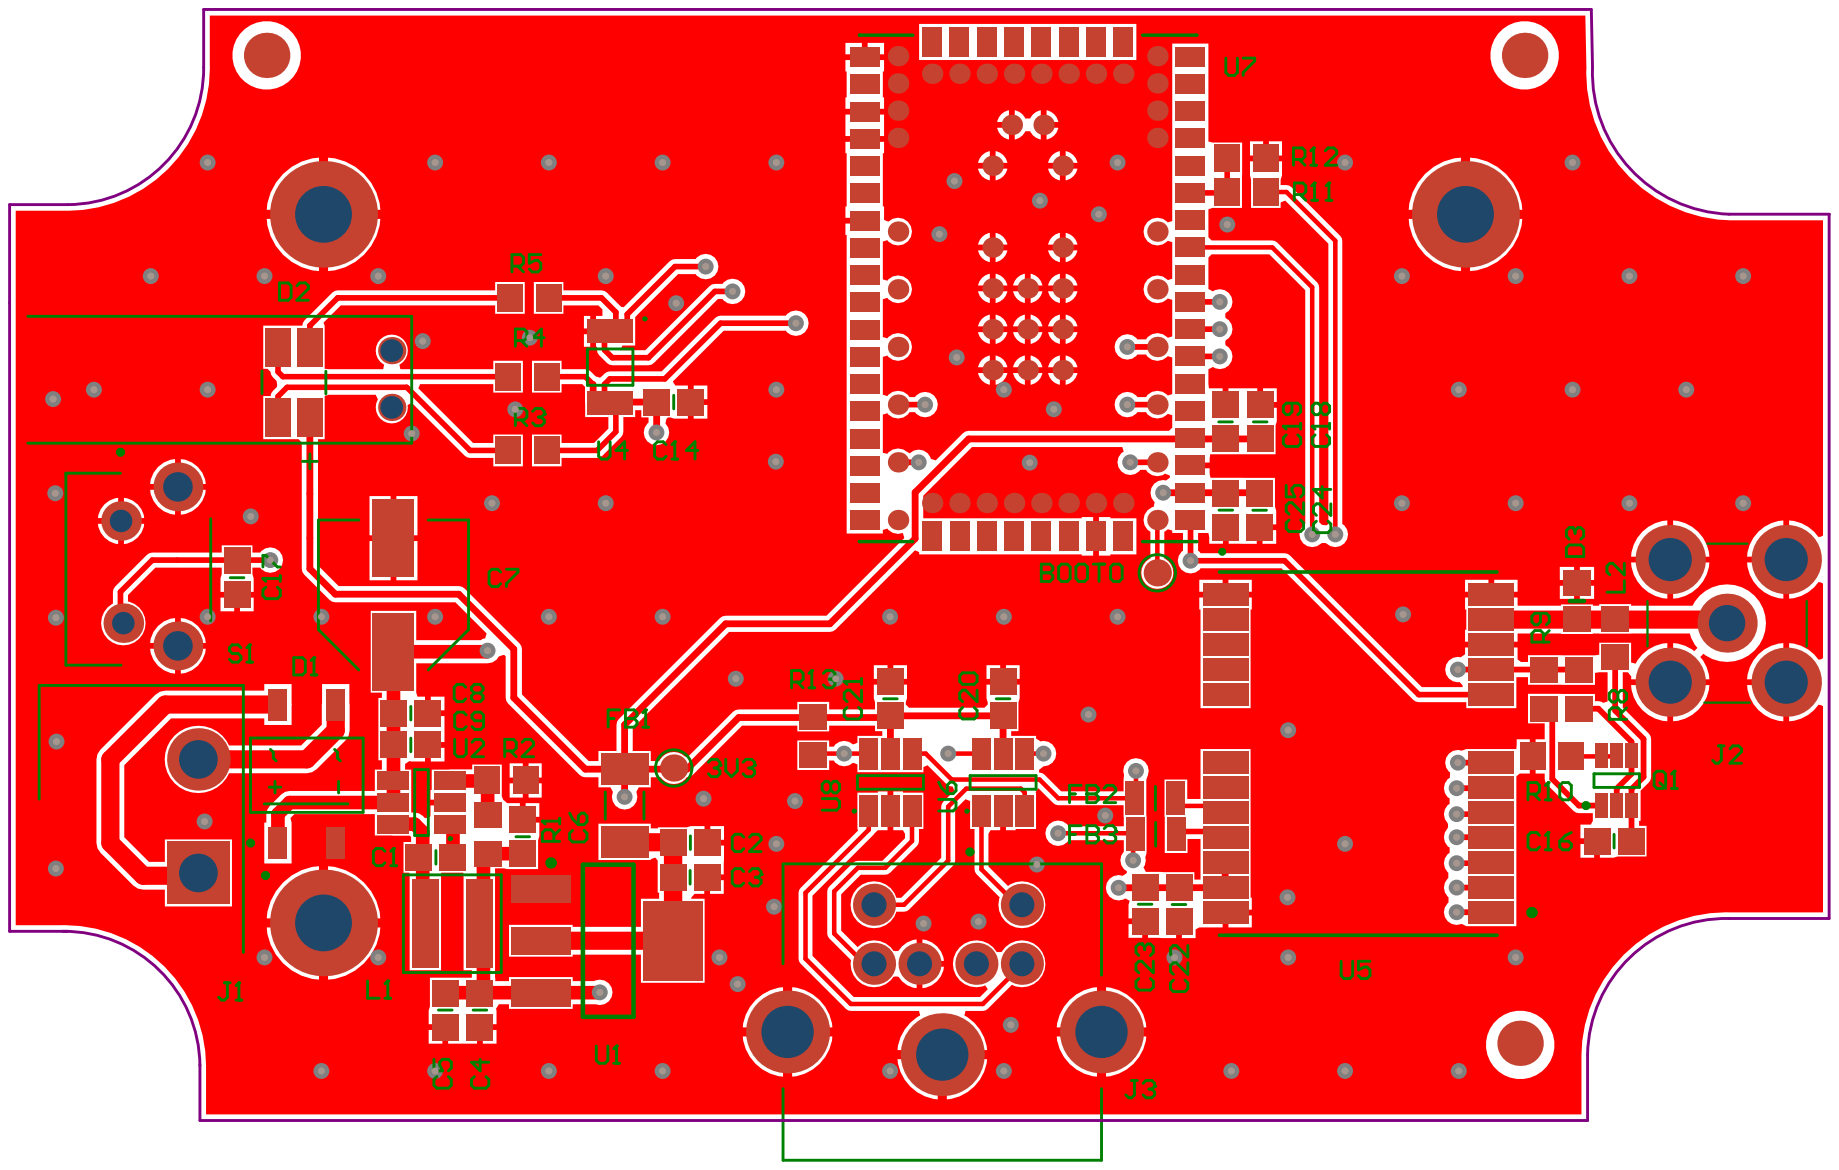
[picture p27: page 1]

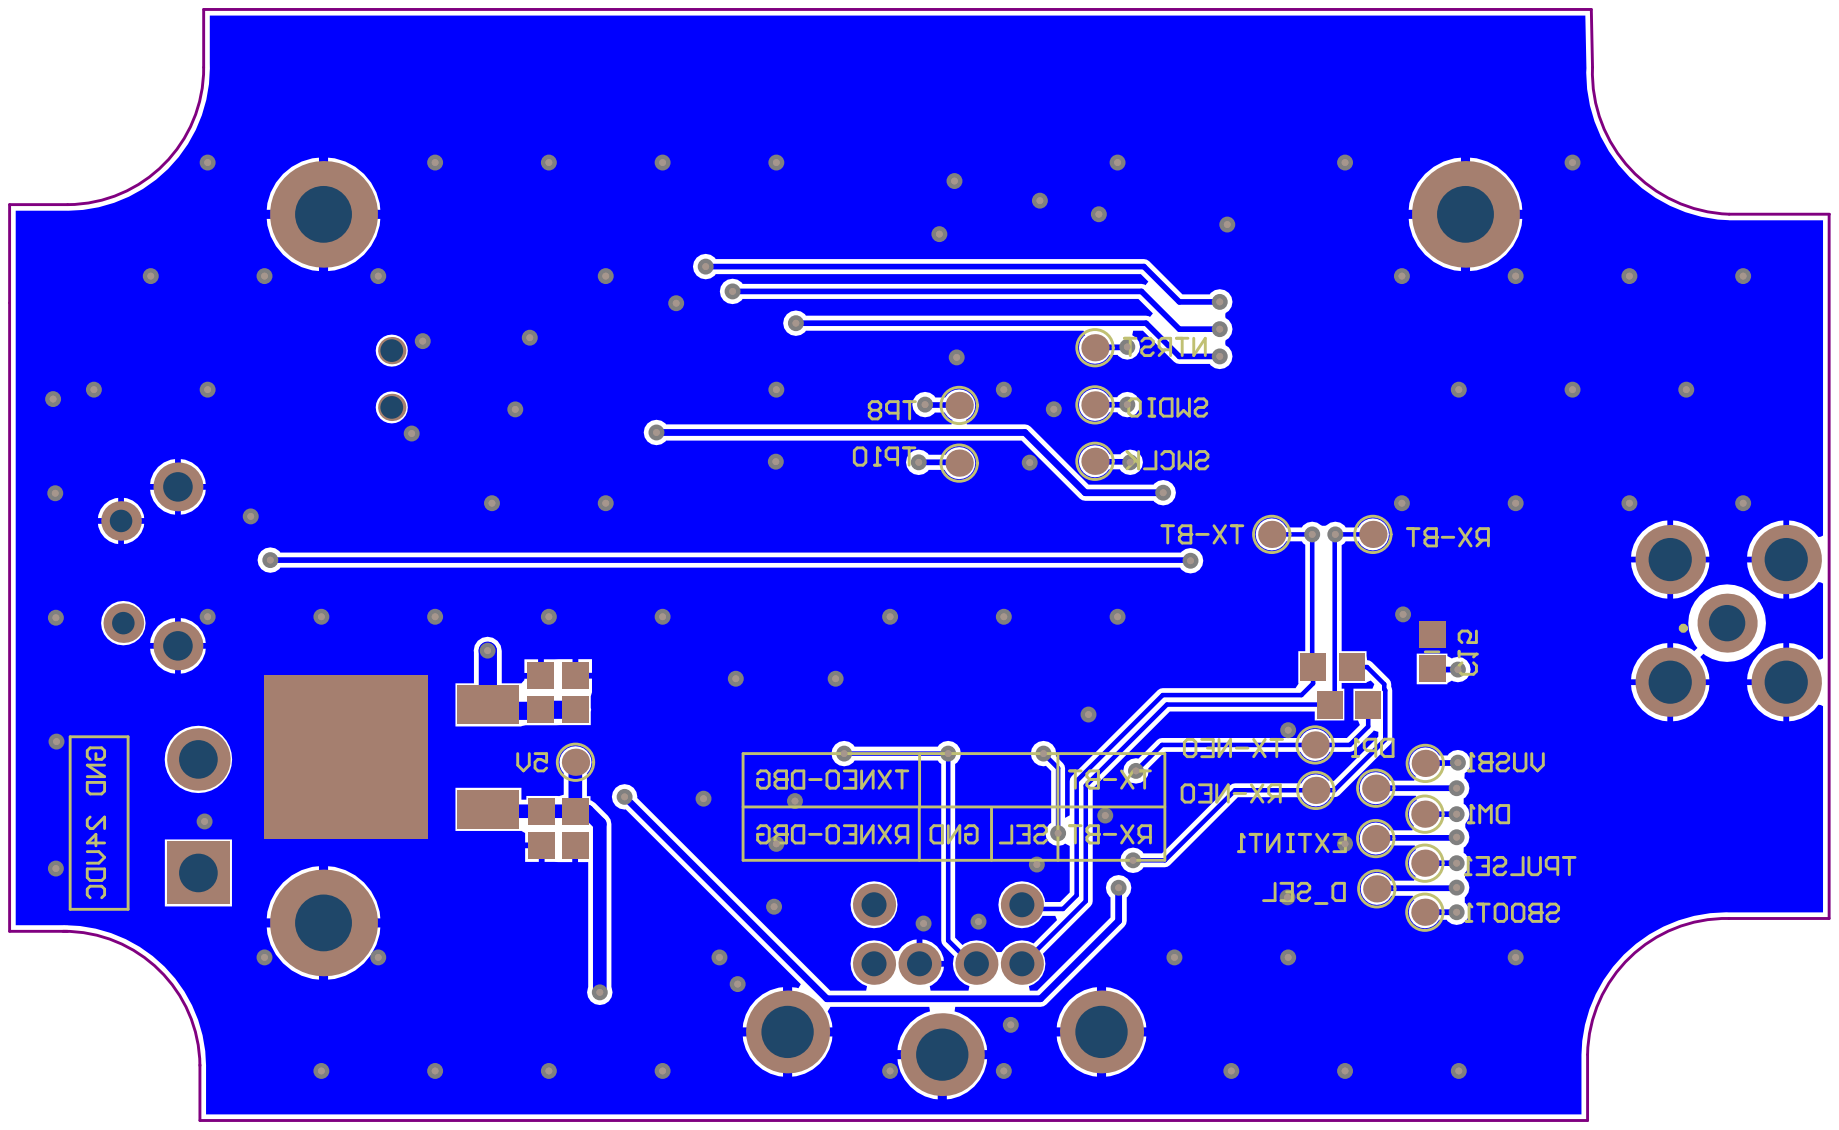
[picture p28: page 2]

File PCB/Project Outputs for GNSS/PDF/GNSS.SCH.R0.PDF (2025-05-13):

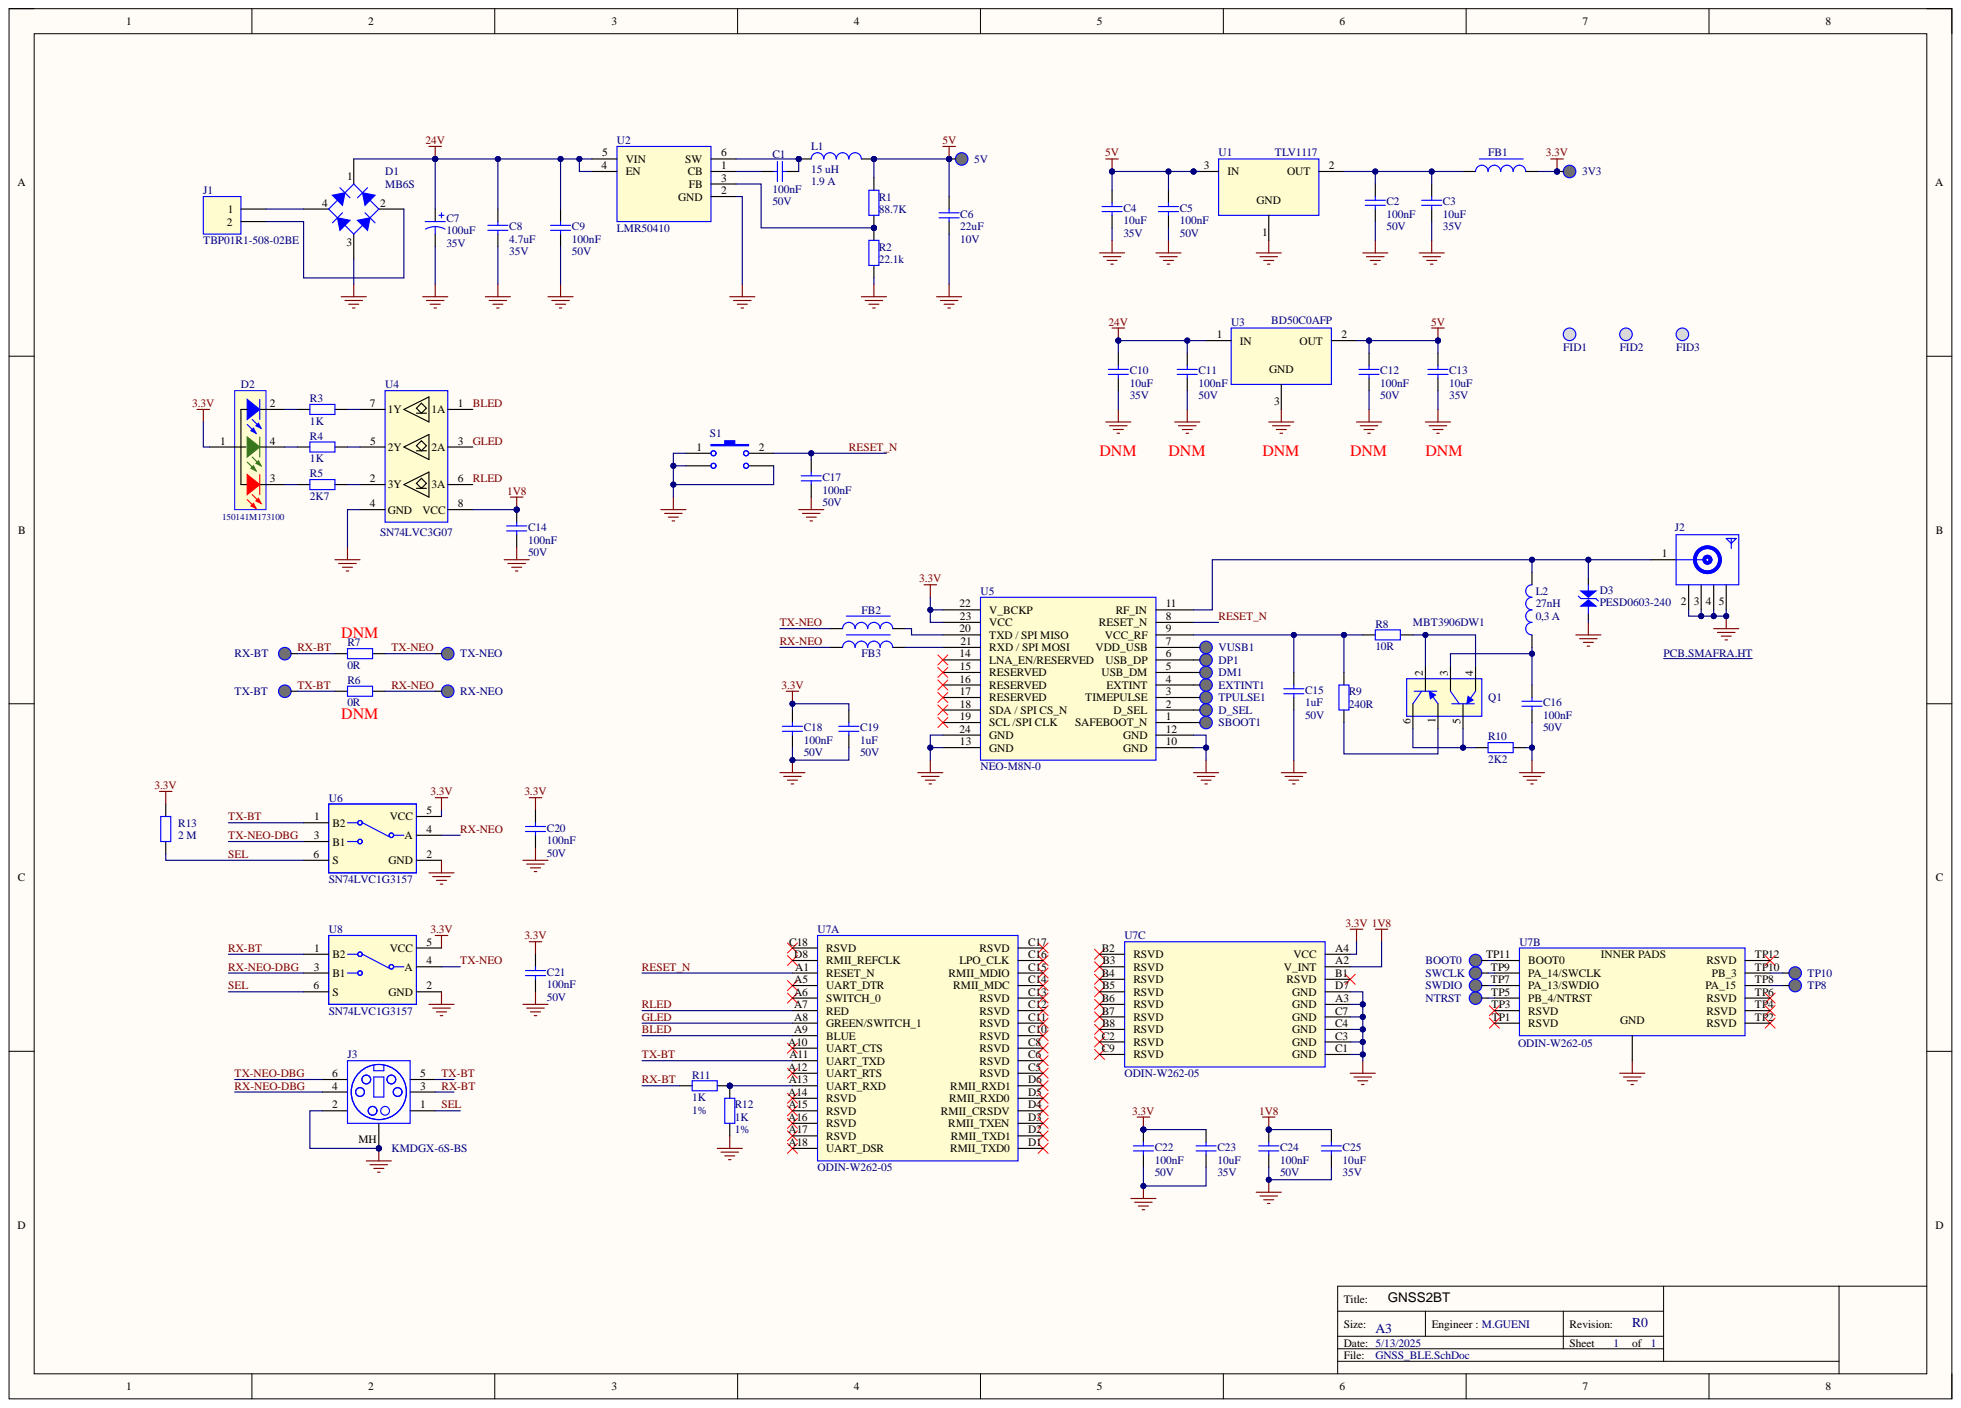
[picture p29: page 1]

TX-NEO RX-NEO-DBG

Size: A3 | Engineer : M.GUENI | Revision: R0

Date: 5/13/2025 | | Sheet 1 of 1

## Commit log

2025-05-13 Refactor code structure for improved readability and maintainability
    [GNSS.BOM.R0.xlsx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]
2025-05-13 Remove obsolete 3D model files to streamline the repository
    [733910083.stp.SLDPRT, Assem1.SLDASM, CUI_DEVICES_TBP01P1-508-02BE.sldprt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]
